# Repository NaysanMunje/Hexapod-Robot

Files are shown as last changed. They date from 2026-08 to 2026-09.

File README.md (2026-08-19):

# Hexapod
a cheap 3D printed hexapod robot using MG996r servos and an esp32.

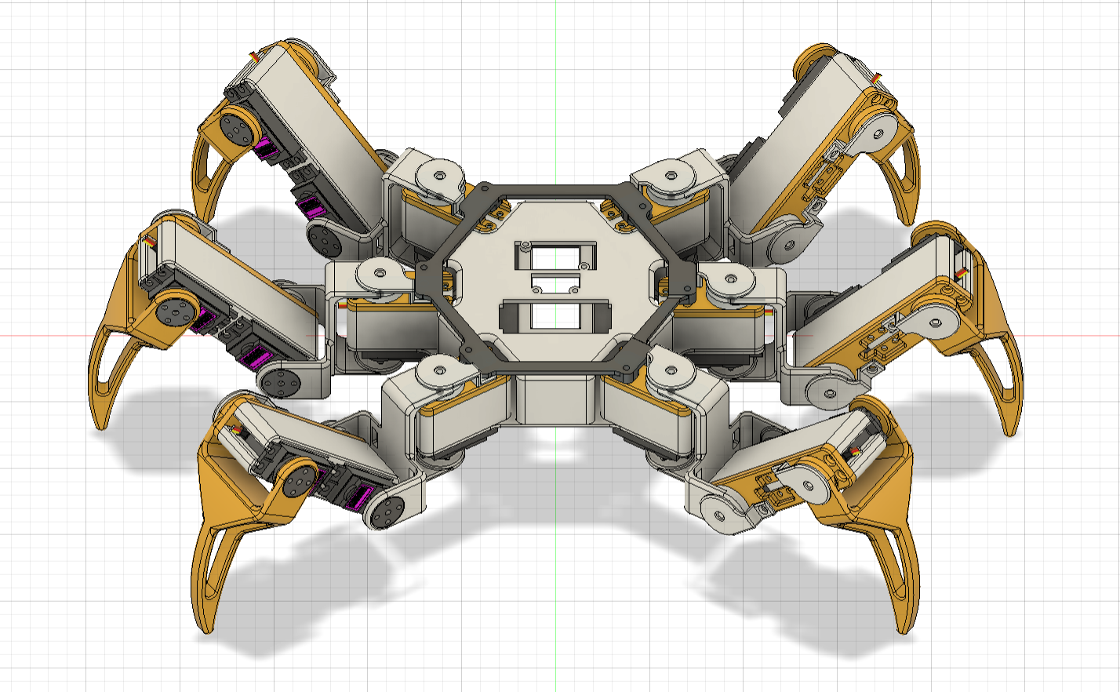
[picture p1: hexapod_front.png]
Hexapod from the front


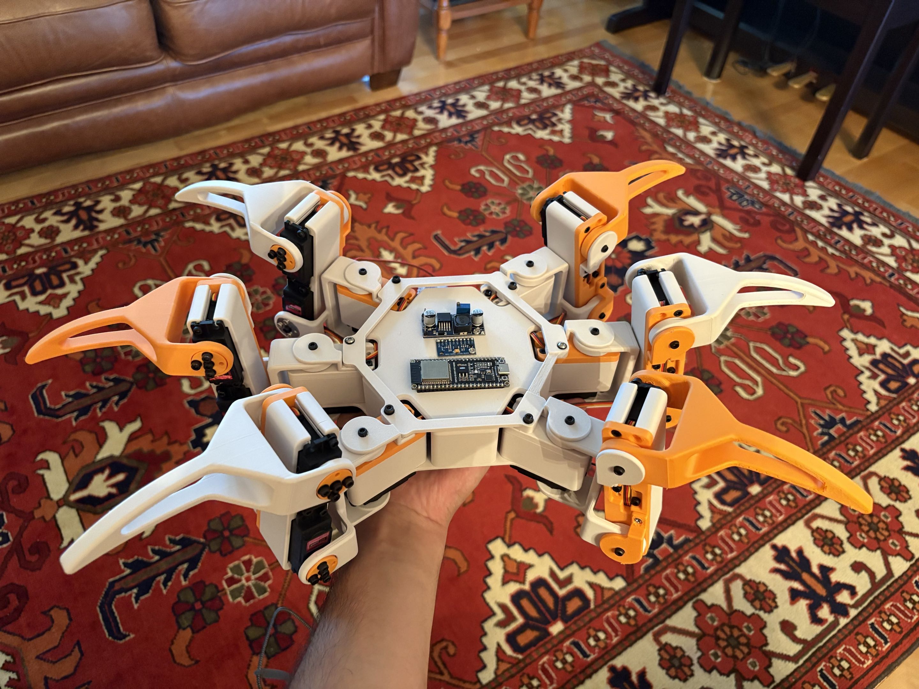
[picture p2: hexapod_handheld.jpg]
Hexapod handheld


How to set up, flash, and run the robot is in **[USAGE.md](USAGE.md)**. Calibration steps are in **[docs/CALIBRATION.md](docs/CALIBRATION.md)**.

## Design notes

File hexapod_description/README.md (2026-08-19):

# Model & preview (`hexapod_description`)

Stick kinematics and URDF matching the firmware. **Offline preview:** open [`view_hexapod.html`](view_hexapod.html) (same gait tabs as `/walk`).

| File | Purpose |
|---|---|
| `view_hexapod.html` | Full robot simulation |
| `view_leg.html` / `view_body.html` | Single leg / chassis |
| `urdf/hexapod.urdf` | Full robot URDF |
| `hips.json` | Hip positions and coxa defaults |

Operator guide: [../USAGE.md](../USAGE.md).

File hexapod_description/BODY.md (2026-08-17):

# Hexapod body (center plate)

## Dimensions (mm)
| Feature | Value |
|---|---|
| Top / bottom edges | **123.215** |
| Other four edges | **79.893** each |
| Top–bottom (flat-to-flat) | **146.564** |
| Left–right tip-to-tip | **186.859** (derived) |
| Height | **30** (hips on the bottom face) |

Opposite sides parallel; left/right symmetric.

## Hip mounts = **vertices** (mm)
Frame: +X forward, +Y left.

| Leg | X | Y |
|-----|---|---|
| **LF** | 73.282 | 61.608 |
| **LM** | 0 | 93.430 |
| **LR** | -73.282 | 61.608 |
| **RF** | 73.282 | -61.608 |
| **RM** | 0 | -93.430 |
| **RR** | -73.282 | -61.608 |

Orientation of each coxa (`yaw0`) is the **mount default**, not radial from center: LM/RM along ±Y; corners perpendicular outward to the adjacent 79.893 mm side. Numbers are in [`hips.json`](hips.json).

## Files
- [`urdf/body.urdf`](urdf/body.urdf)
- [`view_body.html`](view_body.html)
- [`hips.json`](hips.json)

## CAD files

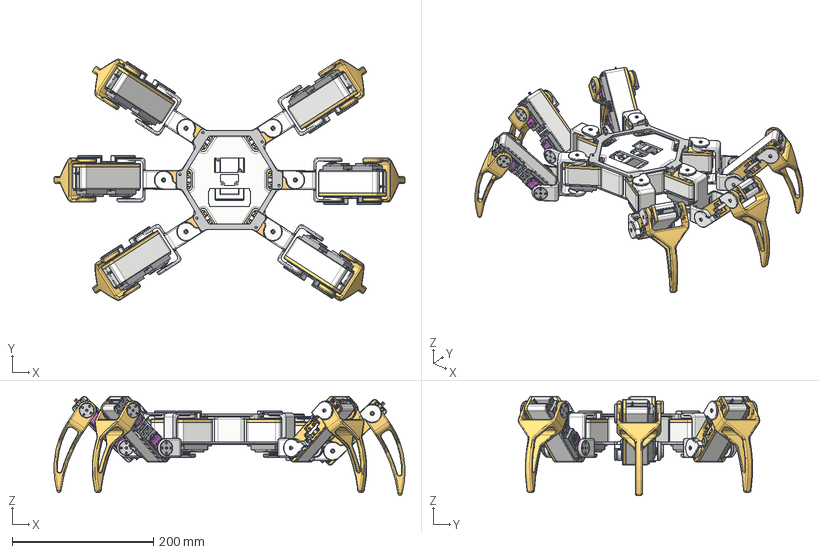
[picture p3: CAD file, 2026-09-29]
FINAL ASSEMBLY.step
497.6 x 342.5 x 140.4 mm
hip servo x 6
hip servo bottom x 6
hip output x 6
thigh link x 6
thigh link bottom plate x 6
shin x 6
bearing insert x 18
servo disc x 18
chassis cap
chassis 2

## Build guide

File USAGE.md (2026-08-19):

# Using the hexapod

This guide takes you from parts on the bench to a walking robot. If something fails, see [docs/TROUBLESHOOTING.md](docs/TROUBLESHOOTING.md).

---

## What you need

| Item | Notes |
|---|---|
| **ESP32-S3 DevKitC-1** | Firmware target in `pca_servo_test/platformio.ini` |
| **18× MG996R-class servos** | One hip, thigh, shin per leg × 6 legs |
| **2× PCA9685** | Addresses **0x40** (default) and **0x41** (A0 bridged to V+) |
| **5 V supply for servos** | Separate from USB; common ground with ESP32 |
| **I²C wiring** | SDA → **GPIO6**, SCL → **GPIO5** |
| **WiFi** | 2.4 GHz network the ESP can join |
| **PC** | [PlatformIO](https://platformio.org/) (VS Code extension or CLI) |

Leg naming on the web UI: **FL, ML, RL** (left) and **FR, MR, RR** (right). Forward is **+X** on the body.

---

## Hardware

### PCA9685 addresses

| Board | I²C address | Channels |
|---|---|---|
| PCA #0 | `0x40` | UI channels 1–16 |
| PCA #1 | `0x41` (A0 jumpered) | UI channels 17–32 |

On boot the serial log must show `PCA0 0x40 ready` and `PCA1 0x41 ready`. If either is **missing/fail**, fix wiring and power before continuing.

### Servo channel map

Each joint has a **UI channel number** (1–32) used on the calibrator page. The full map is in [`pca_servo_test/servo_map.json`](pca_servo_test/servo_map.json). Example:

| Leg | Hip | Thigh | Shin |
|-----|-----|---|---|
| FL | 12 | 8 | 22 |
| ML | 11 | 7 | 21 |
| RL | 10 | 5 | 17 |
| FR | 23 | 19 | 13 |
| MR | 29 | 28 | 9 |
| RR | 26 | 18 | 1 |

If your wiring differs, update `servo_map.json` **and** the `JOINTS[]` table in `src/main.cpp` together (same project; that file is the firmware source of truth for channel numbers).

### Power and safety

- **Never** drive servos from ESP32 3.3 V pins — use the PCA9685 with a proper 5 V servo supply.
- Start calibration with the robot **off the ground** or legs free to move.
- Keep fingers clear when pressing **Start robot** or running **Go MAX/MIN** on the calibrator.
- Stop with **Stop robot** or power off if a joint buzzes against a hard stop.

---

## Software setup

### 1. WiFi credentials

```bash
cd pca_servo_test
```

Copy the example secrets file:

- **Linux / macOS:** `cp include/wifi_secrets.h.example include/wifi_secrets.h`
- **Windows (PowerShell):** `Copy-Item include/wifi_secrets.h.example include/wifi_secrets.h`

Edit `include/wifi_secrets.h` and set `WIFI_SSID` and `WIFI_PASSWORD`.

### 2. Serial port

Default upload port is **COM4** in `platformio.ini`. Change `upload_port` and `monitor_port` to match your board (e.g. `COM3`, `/dev/ttyUSB0`).

Find the port: Device Manager (Windows), `pio device list`, or the PlatformIO toolbar.

### 3. Flash firmware

```bash
pio run -t upload
pio device monitor
```

At 115200 baud you should see:

1. I²C scan finding `0x40` and `0x41`
2. PCA ready messages
3. WiFi connecting, then **`Open http://192.168.x.x`**

Connect your phone or PC to the **same WiFi** and open that URL.

### 4. Pre-loaded calibration (this repo’s robot)

If your hardware matches this build, firmware may already work: on **empty NVS** it loads [`calibration/servo_cal.json`](calibration/servo_cal.json) automatically.

**Check:** calibrator page (`http://<ip>/`) should show **18/18 calibrated**. If counts are lower or motion looks wrong, follow **[docs/CALIBRATION.md](docs/CALIBRATION.md)**.

---

## Web pages

| URL | Use |
|-----|-----|
| `http://<ip>/` | **Calibration** — set DEFAULT/MAX, direction, lock spans |
| `http://<ip>/walk` | **Gaits** — preview, deploy params, start/stop robot |

The walk page loads Three.js from a CDN when you open **Settings** → 3D preview. The browser needs **internet** for that panel only; tabs and robot control work offline once the page is loaded.

---

## Walk page (`/walk`)

### Layout

- **Top tabs:** Walk · Ripple · Wave · Spin · Stretch · Pitch · Crouch · Twist · Roll · Nod · Swirl · Rotate · Control
- **Settings** (overlay): sliders, 3D preview, **Deploy to robot**, **Freeze hips**
- **Start robot / Stop robot** on the main screen (except Control tab, which uses hold-to-move)

### Important behavior

| Action | What it does |
|---|---|
| Move sliders | Updates **preview** (and 3D if Settings open) only |
| **Deploy to robot** | Sends current sliders to the ESP; required before walking |
| **Start robot** | Runs the active tab’s motion on hardware |
| **Stop robot** | Stops gait; parks legs (hips default, shins mid, thighs 75% toward min) |
| **Freeze hips** | Coxa stay at default; thighs/shins still walk (good first setting) |

Sliders do **not** live-update the robot until you deploy.

### Recommended first walk

1. Tab: **Walk**
2. Settings: leave defaults if unsure — **freq 0.8 Hz**, **stride 60 mm**, **lift 30 mm**, **height 95 mm**, **radius 140 mm**, **splay 22°**, **Freeze hips** on
3. **Deploy to robot**
4. Lift robot clear of the table → **Start robot**
5. If motion is smooth, try lowering stride or freq; if feet drag, increase lift slightly
6. **Stop robot** when done

### Tabs (short)

| Tab | Motion |
|-----|---|
| **Walk** | Tripod gait (3+3), 50% duty — default forward walk |
| **Ripple** | One leg at a time, alternating sides rear→front |
| **Wave** | One leg at a time clockwise around the body |
| **Spin** | In-place yaw; set **turn rate** in Settings; stride should be 0 |
| **Stretch** | Feet planted · lean left ↔ right (**Start robot**) |
| **Pitch** | Feet planted · lean forward ↔ back |
| **Crouch** | Feet planted · squat up ↔ down |
| **Twist** | Feet planted · yaw left ↔ right (uncheck Freeze hips) |
| **Roll** | Feet planted · chassis tilts left ↔ right (~14°) |
| **Nod** | Feet planted · chassis tips nose ↔ tail (~14°) |
| **Swirl** | Feet planted · chassis tilts while circling (most motion) |
| **Rotate** | Feet planted · lean in a circle (body stays level) |
| **Control** | Hold D-pad to walk; hold **↺ CCW** / **↻ CW** to spin; release to stop |

Switching away from a locomotion tab **stops** the robot if it was running.

### Spin and Control

- **Spin tab:** deploy with **turn rate** (default 20°/s), **stride 0**, then **Start robot**
- **Control tab:** turn rate comes from Settings; hold spin buttons while deployed

Keep turn rate modest (~15–25°/s) until you confirm hips are not saturating.

---

## Calibration (summary)

Full procedure: **[docs/CALIBRATION.md](docs/CALIBRATION.md)**.

Quick rules:

1. **Hip:** mechanical default → **Save DEFAULT** → set direction (+CCW from above)
2. **Thigh / shin:** folded hard stop → **Save MAX** → set direction (+pulse opens toward straight)
3. After all 12 thighs and 12 shins have MAX saved: **Lock thighs/shins to shortest max→min span**
4. Use **Go MIN / Go MID / Go MAX** on each joint to verify before walking

Reference: **[pca_servo_test/JOINT_CONVENTION.md](pca_servo_test/JOINT_CONVENTION.md)**.

---

## Offline simulation

Open [`hexapod_description/view_hexapod.html`](hexapod_description/view_hexapod.html) locally. Tune gaits and clearances without hardware. Defaults match the firmware walk page.

Other viewers: `view_leg.html` (single leg), `view_body.html` (chassis).

---

## Maintainers: editing the walk UI

After changing `pca_servo_test/www/walk.html`:

```bash
cd pca_servo_test
python gen_walk_html.py
pio run -t upload
```

After re-calibrating and downloading JSON from the robot:

```bash
# save to calibration/servo_cal.json, then:
python gen_cal_backup.py
pio run -t upload
```

See [calibration/README.md](calibration/README.md).

---

## Checklist before first walk

- [ ] Both PCA boards detected on serial boot
- [ ] Calibrator shows 18/18 (or calibration finished per CALIBRATION.md)
- [ ] **Lock spans** run for thighs and shins
- [ ] **Deploy to robot** clicked after slider changes
- [ ] Robot supported or clear of obstacles
- [ ] **Stop robot** tested

Done — use [docs/TROUBLESHOOTING.md](docs/TROUBLESHOOTING.md) if anything misbehaves.

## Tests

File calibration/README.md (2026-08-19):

# Calibration backup

Example PWM table for this robot: [`servo_cal.json`](servo_cal.json).

| Task | Doc |
|---|-----|
| Calibrate a new build | [../docs/CALIBRATION.md](../docs/CALIBRATION.md) |
| Joint angles & PWM math | [../pca_servo_test/JOINT_CONVENTION.md](../pca_servo_test/JOINT_CONVENTION.md) |

**Restore on device:** calibrator → **Restore snapshot**, or auto-load on empty NVS.

**Refresh backup after re-cal:** download JSON from robot → replace `servo_cal.json` → `python gen_cal_backup.py` in `pca_servo_test/` → re-flash.

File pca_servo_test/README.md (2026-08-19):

# Firmware (`pca_servo_test`)

| Task | Doc |
|---|-----|
| Flash, walk UI, first steps | [../USAGE.md](../USAGE.md) |
| Calibrate servos | [../docs/CALIBRATION.md](../docs/CALIBRATION.md) |
| Fix problems | [../docs/TROUBLESHOOTING.md](../docs/TROUBLESHOOTING.md) |
| Joint convention | [JOINT_CONVENTION.md](JOINT_CONVENTION.md) |
| Channel wiring | [servo_map.json](servo_map.json) |

```bash
cp include/wifi_secrets.h.example include/wifi_secrets.h   # then edit WiFi
pio run -t upload
```

After editing `www/walk.html`: `python gen_walk_html.py` then re-flash.

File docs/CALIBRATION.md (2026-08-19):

# Servo calibration

Follow this on a **new build**, after rewiring, or if legs move the wrong way. The robot should be **off the ground** and powered.

**Reference while you work:** [JOINT_CONVENTION.md](../pca_servo_test/JOINT_CONVENTION.md) (angles, signs, PWM rules).

**Channel numbers:** [servo_map.json](../pca_servo_test/servo_map.json).

---

## Before you start

1. Flash firmware and open **`http://<esp-ip>/`** (calibrator).
2. Serial log should show `PCA0 0x40 ready` and `PCA1 0x41 ready`.
3. Status line should show how many joints are calibrated (goal: **18/18**).

If this repo’s hardware matches yours, try a quick test first: firmware may load [servo_cal.json](../calibration/servo_cal.json) from flash backup. Use **Restore snapshot from firmware backup** on the calibrator page. If all legs move correctly on **Go MID**, you can skip to the lock-span step below.

---

## Calibrator page overview

Each joint row has:

| Control | Purpose |
|---|---|
| Slider + **− / +** | Nudge raw PWM (80–520 µs ticks) |
| **Save DEFAULT** (hip only) | Current pose = model 0° |
| **Save MAX** (thigh/shin) | Current folded hard stop = model MAX |
| **← MIN / MIN →** (or **← +CCW / +CCW →** on hips) | Set direction: higher PWM toward model MIN |
| **Go MAX / Go MID / Go MIN** | Jump to calibrated endpoints |

Global buttons at the top:

- **Lock thighs/shins to shortest max→min span** — run after all thighs and shins have MAX saved
- **All … → MID/MIN/MAX** — test groups
- **Restore snapshot** — load committed JSON from firmware

---

## Order of work

Work **one joint at a time** or leg-by-leg (hip → thigh → shin on FL, then next leg, …). Thighs and shins **must** be calibrated before walking.

### Step 1 — All hips (6 joints)

For each hip:

1. Rotate coxa by hand or slider until the leg matches the **mount default** (middle legs along ±Y; corners outward — see JOINT_CONVENTION).
2. Click **Save DEFAULT**.
3. Tap **← +CCW** or **+CCW →** so that **increasing PWM moves the foot clockwise from above** (toward model MIN = −45°).
4. Test: **Go MAX** ≈ CCW from default; **Go MIN** ≈ CW from default.

Hips do **not** use Save MAX at a mechanical stop.

### Step 2 — All thighs (6 joints)

For each thigh:

1. Move to the **folded hard stop** (femur up against hip / maximum fold).
2. Click **Save MAX**.
3. Set direction so **+pulse opens the thigh toward flat** (model MIN = straight).
4. Test: **Go MIN** extends thigh; **Go MID** halfway; **Go MAX** folded.

### Step 3 — All shins (6 joints)

For each shin:

1. Move to **folded hard stop** (foot under thigh).
2. Click **Save MAX**.
3. Set direction so **+pulse straightens** the shin (model MIN).
4. Test: **Go MIN** straight; **Go MID** halfway; **Go MAX** folded.

### Step 4 — Lock spans

When all 12 thighs and 12 shins have `ref` saved:

1. Click **Lock thighs/shins to shortest max→min span**.
2. Serial / status should confirm locked spans (this build uses ~226 ticks thigh, ~203 shin when all legs match).

Locking keeps all six legs on the same usable range even if one servo has slightly less travel.

### Step 5 — Verify

1. **All calibrated → MID / DEFAULT** — robot should sit in a symmetric rest-like pose.
2. Move each leg through **Go MIN** and **Go MAX** once — no buzzing for more than a moment at stops.
3. Download **calibration JSON** from the page and save to `calibration/servo_cal.json` if you want the backup committed (optional).

---

## Direction mistakes (most common error)

Symptom: **Go MIN** moves the wrong way or hits a stop immediately.

Fix: flip **MIN ← / → MIN** (or hip **+CCW** side), then re-test MIN/MID/MAX. You do **not** need to re-save ref unless the reference pose was wrong.

---

## After calibration

1. Open **`/walk`**
2. **Deploy to robot**
3. Try **Walk** tab with **Freeze hips** on and low stride

If gait IK reports unreachable feet, check **height**, **radius**, and **lift** in Settings — start from defaults (95 mm height, 140 mm radius).

---

## Saving calibration into firmware

To bake your table into the next flash for other boards:

```bash
cd pca_servo_test
python gen_cal_backup.py   # reads ../calibration/servo_cal.json
pio run -t upload
```

Empty NVS on a new chip will then auto-restore your snapshot on boot.

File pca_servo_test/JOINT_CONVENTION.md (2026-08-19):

# Joint rotation standard (model ↔ servos)

**Calibrating hardware?** Use the step-by-step guide: [docs/CALIBRATION.md](../docs/CALIBRATION.md).

Robot frame: **+X forward, +Y left, +Z up**.  
All six legs use the **same** kinematic signs (no left/right axis flip in the model). Servo mounting mirrors are handled only by each joint’s **direction** flag in calibration.

Naming: UI `FL/ML/RL/FR/MR/RR` = model `LF/LM/LR/RF/RM/RR`.

PWM snapshot for this robot: [`../calibration/servo_cal.json`](../calibration/servo_cal.json).

---

## Zero poses

| Joint | Angle 0 (model) |
|---|---|
| **Hip** | Mount default: middle legs horizontal (±Y); corners perpendicular **outward** to the adjacent **79.893 mm** body edge (`yaw0` in `hips.json`) |
| **Thigh** | Femur horizontal in the coxa’s radial plane (collinear with coxa, flat) |
| **Shin** | Shin collinear with thigh (fully open) |

---

## Hip (special)

Hips are **not** calibrated to min/max stops. Only the **mount default** is saved (mid / model 0°).

- Side buttons mark which slider direction is **+CCW from above** (`← +CCW` / `+CCW →`).
- Gait later uses `pulse = default + scale * (−θ)` with that direction (θ = model hip angle).
- Soft ±45° limits can be applied in software without calibrating those PWM ends.

## Thigh / shin

Still calibrate from **MAX** hard stop; MIN = remaining travel; MID = midpoint.
Side buttons: **MIN ←** / **→ MIN**.

---

## Positive model angles (same on every leg)

| Joint | + direction | Range | MAX | MIN |
|---|---|---|-----|-----|
| **Hip** | **CCW from above** (right-hand about +Z). Foot swings counterclockwise around the body from the default. | −45° … +45° | +45° (CCW) | −45° (CW) |
| **Thigh** | Femur tip / knee **rises** (pitch up from horizontal) | 0° … 102.5° | **102.5°** hard stop (thigh folded toward hip) | **0°** (straight / flat) |
| **Shin** | Foot folds **back under** the thigh (knee bend) | 0° … 122.4° | **122.4°** hard stop (shin folded) | **0°** (straight with thigh) |

These are exactly the signs used by `view_hexapod.html` IK / gait.

---

## How to set servo direction in the calibrator

Calibration stores one reference pulse, then derives the rest. **Direction** answers:

> Does **increasing PWM** move the joint toward **model MIN**?

| `dir` | Meaning |
|---|---|
| **+ pulse** | Higher PWM → toward model MIN |
| **− pulse** | Higher PWM → toward model MAX (i.e. lower PWM → MIN) |

### Hip
1. Align coxa to **mount default** → **Save DEFAULT** (this is model 0° / mid).
2. Nudge PWM. Watch the foot from above.
3. Pick direction so **+pulse moves CW from above** (toward model MIN = −45°).
4. Check: **Go MAX** = CCW from default; **Go MIN** = CW from default.

### Thigh
1. Ease to the **folded hard stop** (thigh up against hip) → **Save MAX**.
2. Pick direction so **+pulse opens the thigh toward flat/straight** (model MIN).
3. Check: **Go MIN** lowers/extends the thigh; **Go MID** is halfway.

### Shin
1. Ease to the **folded hard stop** → **Save MAX**.
2. Pick direction so **+pulse opens the shin toward straight** (model MIN).
3. Check: **Go MIN** straightens the shin; **Go MID** is halfway.

---

## Mapping model angle → PWM (firmware)

Once `ref` and `dir` are set:

**Hip** (`ref` = default):  
`pulse(θ) = ref + dir * ticks_per_deg * (−θ)`  
so θ = +45° (MAX) and θ = −45° (MIN) land on the derived endpoints.

**Thigh / shin** (`ref` = MAX):  
`pulse(θ) = ref + dir * ticks_per_deg * (θ_max − θ)`  
so θ = θ_max → `ref`, θ = 0 → derived MIN.

(`ticks_per_deg ≈ 400/180` with the current PCA pulse scale.)

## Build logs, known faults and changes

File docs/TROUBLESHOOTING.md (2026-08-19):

# Troubleshooting

Symptoms → checks → fixes. Start with serial monitor output (115200 baud) while reproducing the issue.

---

## WiFi / web page

| Symptom | Fix |
|---|-----|
| Serial stuck at `Connecting...` | Wrong SSID/password in `wifi_secrets.h`; ESP must be on **2.4 GHz**; re-flash after edit |
| No IP printed | Wait 30 s; check router; try serial-only calibrator features if WiFi fails |
| Phone cannot open `http://<ip>` | PC/phone on **same network** as ESP; disable VPN; try IP from serial exactly |
| `/walk` loads but 3D blank | Browser needs **internet** for Three.js CDN; rest of page still works |

---

## I²C / PCA9685

| Symptom | Fix |
|---|-----|
| `PCA0 missing/fail` | Check SDA/SCL (GPIO6/5), 3.3 V logic, common ground |
| Only one board found | Second board needs **A0 → V+** for address **0x41** |
| I²C scan finds nothing | Loose wires, wrong pins, or flat battery on ESP32 |
| One leg dead, others OK | Match [servo_map.json](../pca_servo_test/servo_map.json) wiring to UI channel; test with calibrator slider on that channel |

---

## Servos

| Symptom | Fix |
|---|-----|
| Servo buzzes at stop | Normal briefly at MIN/MAX; back off slider; recalibrate MAX if stop moved |
| Wrong joint moves | Wrong channel in `servo_map.json` / firmware `JOINTS[]` |
| Leg moves backward vs preview | Flip **dir** on that joint (see [CALIBRATION.md](CALIBRATION.md)) |
| Jerky or weak motion | Servo power supply undervoltage; add bulk cap; separate 5 V from USB |
| All servos twitch at boot | Expected short pulse; ensure supply can deliver 18 servos |

---

## Calibration count

| Symptom | Fix |
|---|-----|
| Less than 18/18 calibrated | Finish hips (DEFAULT), thighs/shins (MAX) per [CALIBRATION.md](CALIBRATION.md) |
| Restore did nothing | Click **Restore snapshot from firmware backup** on `/` or re-flash after `gen_cal_backup.py` |
| Values look random | NVS corrupt — restore snapshot or full re-cal |

---

## Walk / gait (`/walk`)

| Symptom | Fix |
|---|-----|
| Sliders move preview but not robot | Click **Deploy to robot** |
| Start does nothing | Deploy first; check 18/18 calibrated; serial for errors |
| Robot walks before Start | Only **Start robot** runs motion; switching tabs stops robot |
| Feet don’t lift | Increase **lift**; decrease **stride** or **freq** |
| Hips pegged / leg skips | Lower **turn** rate; disable spin until walk is good; try **Freeze hips** |
| “Unreachable” / bad pose in status | Lower **height** or **radius**; increase **splay** on corners |
| Stretch/Rotate won’t run | Must press **Start robot** on that tab (no auto-start) |
| Control hold doesn’t move | Deploy first; hold D-pad or spin buttons; release to stop |
| Stop pose wrong | **Stop robot** parks thighs between mid and min; hips default — expected |

---

## Flash / PlatformIO

| Symptom | Fix |
|---|-----|
| Upload fails | Fix `upload_port` in `platformio.ini`; hold BOOT if needed; USB cable data-capable |
| `pio` not found | Install PlatformIO IDE extension or CLI |
| Windows `cp` fails | Use `Copy-Item` for `wifi_secrets.h` |

---

## Simulation vs robot diverge

| Symptom | Fix |
|---|-----|
| Preview OK, hardware wrong | Calibration / direction issue, not gait math |
| Preview wrong | Open `hexapod_description/view_hexapod.html`; compare link lengths in [hips.json](../hexapod_description/hips.json) to your physical robot |

---

## Still stuck?

1. Serial log from cold boot through first **Start robot**
2. Calibrator **Download calibration JSON** attached to an issue
3. Confirm PCA scan, calibrated count, and which tab + slider values were deployed

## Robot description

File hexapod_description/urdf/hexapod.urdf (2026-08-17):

<?xml version="1.0"?>
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
<robot name="hexapod">
  <link name="base_link">
    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
  </link>

  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
  <joint name="LF_attach" type="fixed">
    <parent link="base_link"/>
    <child link="LF_hip"/>
    <origin xyz="0.073282 0.061608 0" rpy="0 0 1.161125"/>
  </joint>
  <link name="LF_hip"/>

  <joint name="LF_coxa_joint" type="revolute">
    <parent link="LF_hip"/>
    <child link="LF_coxa"/>
    <origin xyz="0 0 0" rpy="0 0 0"/>
    <axis xyz="0 0 1"/>
    <limit lower="-0.785" upper="0.785" effort="10" velocity="3"/>
  </joint>
  <link name="LF_coxa">
    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
  </link>

  <joint name="LF_femur_joint" type="revolute">
    <parent link="LF_coxa"/>
    <child link="LF_femur"/>
    <origin xyz="0.053 0 0" rpy="0 0 0"/>
    <axis xyz="0 1 0"/>
    <limit lower="-1.789" upper="0" effort="10" velocity="3"/>
  </joint>
  <link name="LF_femur">
    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
  </link>

  <joint name="LF_knee_joint" type="revolute">
    <parent link="LF_femur"/>
    <child link="LF_shin1"/>
    <origin xyz="0.07736 0 0" rpy="0 0 0"/>
    <axis xyz="0 1 0"/>
    <limit lower="0" upper="2.136" effort="10" velocity="3"/>
  </joint>
  <link name="LF_shin1">
    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
  </link>

  <joint name="LF_shin1_shin2" type="fixed">
    <parent link="LF_shin1"/>
    <child link="LF_shin2"/>
    <origin xyz="0.022358 0 0" rpy="0 -0.2234 0"/>
  </joint>
  <link name="LF_shin2">
    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
  </link>

  <joint name="LF_shin2_shin3" type="fixed">
    <parent link="LF_shin2"/>
    <child link="LF_shin3"/>
    <origin xyz="0.071518 0 0" rpy="0 -0.3508 0"/>
  </joint>
  <link name="LF_shin3">
    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
  </link>

  <joint name="LF_foot_fixed" type="fixed">
    <parent link="LF_shin3"/>
    <child link="LF_foot"/>
    <origin xyz="0.03114 0 0" rpy="0 0 0"/>
  </joint>
  <link name="LF_foot">
    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
  </link>

  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
  <joint name="LM_attach" type="fixed">
    <parent link="base_link"/>
    <child link="LM_hip"/>
    <origin xyz="0.000000 0.093430 0" rpy="0 0 1.570796"/>
  </joint>
  <link name="LM_hip"/>

  <joint name="LM_coxa_joint" type="revolute">
    <parent link="LM_hip"/>
    <child link="LM_coxa"/>
    <origin xyz="0 0 0" rpy="0 0 0"/>
    <axis xyz="0 0 1"/>
    <limit lower="-0.785" upper="0.785" effort="10" velocity="3"/>
  </joint>
  <link name="LM_coxa">
    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
  </link>

  <joint name="LM_femur_joint" type="revolute">
    <parent link="LM_coxa"/>
    <child link="LM_femur"/>
    <origin xyz="0.053 0 0" rpy="0 0 0"/>
    <axis xyz="0 1 0"/>
    <limit lower="-1.789" upper="0" effort="10" velocity="3"/>
  </joint>
  <link name="LM_femur">
    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
  </link>

  <joint name="LM_knee_joint" type="revolute">
    <parent link="LM_femur"/>
    <child link="LM_shin1"/>
    <origin xyz="0.07736 0 0" rpy="0 0 0"/>
    <axis xyz="0 1 0"/>
    <limit lower="0" upper="2.136" effort="10" velocity="3"/>
  </joint>
  <link name="LM_shin1">
    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
  </link>

  <joint name="LM_shin1_shin2" type="fixed">
    <parent link="LM_shin1"/>
    <child link="LM_shin2"/>
    <origin xyz="0.022358 0 0" rpy="0 -0.2234 0"/>
  </joint>
  <link name="LM_shin2">
    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
  </link>

  <joint name="LM_shin2_shin3" type="fixed">
    <parent link="LM_shin2"/>
    <child link="LM_shin3"/>
    <origin xyz="0.071518 0 0" rpy="0 -0.3508 0"/>
  </joint>
  <link name="LM_shin3">
    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
  </link>

  <joint name="LM_foot_fixed" type="fixed">
    <parent link="LM_shin3"/>
    <child link="LM_foot"/>
    <origin xyz="0.03114 0 0" rpy="0 0 0"/>
  </joint>
  <link name="LM_foot">
    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
  </link>

  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
  <joint name="LR_attach" type="fixed">
    <parent link="base_link"/>
    <child link="LR_hip"/>
    <origin xyz="-0.073282 0.061608 0" rpy="0 0 1.980468"/>
  </joint>
  <link name="LR_hip"/>

  <joint name="LR_coxa_joint" type="revolute">
    <parent link="LR_hip"/>
    <child link="LR_coxa"/>
    <origin xyz="0 0 0" rpy="0 0 0"/>
    <axis xyz="0 0 1"/>
    <limit lower="-0.785" upper="0.785" effort="10" velocity="3"/>
  </joint>
  <link name="LR_coxa">
    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
  </link>

  <joint name="LR_femur_joint" type="revolute">
    <parent link="LR_coxa"/>
    <child link="LR_femur"/>
    <origin xyz="0.053 0 0" rpy="0 0 0"/>
    <axis xyz="0 1 0"/>
    <limit lower="-1.789" upper="0" effort="10" velocity="3"/>
  </joint>
  <link name="LR_femur">
    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
  </link>

  <joint name="LR_knee_joint" type="revolute">
    <parent link="LR_femur"/>
    <child link="LR_shin1"/>
    <origin xyz="0.07736 0 0" rpy="0 0 0"/>
    <axis xyz="0 1 0"/>
    <limit lower="0" upper="2.136" effort="10" velocity="3"/>
  </joint>
  <link name="LR_shin1">
    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
  </link>

  <joint name="LR_shin1_shin2" type="fixed">
    <parent link="LR_shin1"/>
    <child link="LR_shin2"/>
    <origin xyz="0.022358 0 0" rpy="0 -0.2234 0"/>
  </joint>
  <link name="LR_shin2">
    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
  </link>

  <joint name="LR_shin2_shin3" type="fixed">
    <parent link="LR_shin2"/>
    <child link="LR_shin3"/>
    <origin xyz="0.071518 0 0" rpy="0 -0.3508 0"/>
  </joint>
  <link name="LR_shin3">
    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
  </link>

  <joint name="LR_foot_fixed" type="fixed">
    <parent link="LR_shin3"/>
    <child link="LR_foot"/>
    <origin xyz="0.03114 0 0" rpy="0 0 0"/>
  </joint>
  <link name="LR_foot">
    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
  </link>

  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
  <joint name="RF_attach" type="fixed">
    <parent link="base_link"/>
    <child link="RF_hip"/>
    <origin xyz="0.073282 -0.061608 0" rpy="0 0 -1.161125"/>
  </joint>
  <link name="RF_hip"/>

  <joint name="RF_coxa_joint" type="revolute">
    <parent link="RF_hip"/>
    <child link="RF_coxa"/>
    <origin xyz="0 0 0" rpy="0 0 0"/>
    <axis xyz="0 0 1"/>
    <limit lower="-0.785" upper="0.785" effort="10" velocity="3"/>
  </joint>
  <link name="RF_coxa">
    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
  </link>

  <joint name="RF_femur_joint" type="revolute">
    <parent link="RF_coxa"/>
    <child link="RF_femur"/>
    <origin xyz="0.053 0 0" rpy="0 0 0"/>
    <axis xyz="0 1 0"/>
    <limit lower="-1.789" upper="0" effort="10" velocity="3"/>
  </joint>
  <link name="RF_femur">
    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
  </link>

  <joint name="RF_knee_joint" type="revolute">
    <parent link="RF_femur"/>
    <child link="RF_shin1"/>
    <origin xyz="0.07736 0 0" rpy="0 0 0"/>
    <axis xyz="0 1 0"/>
    <limit lower="0" upper="2.136" effort="10" velocity="3"/>
  </joint>
  <link name="RF_shin1">
    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
  </link>

  <joint name="RF_shin1_shin2" type="fixed">
    <parent link="RF_shin1"/>
    <child link="RF_shin2"/>
    <origin xyz="0.022358 0 0" rpy="0 -0.2234 0"/>
  </joint>
  <link name="RF_shin2">
    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
  </link>

  <joint name="RF_shin2_shin3" type="fixed">
    <parent link="RF_shin2"/>
    <child link="RF_shin3"/>
    <origin xyz="0.071518 0 0" rpy="0 -0.3508 0"/>
  </joint>
  <link name="RF_shin3">
    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
  </link>

  <joint name="RF_foot_fixed" type="fixed">
    <parent link="RF_shin3"/>
    <child link="RF_foot"/>
    <origin xyz="0.03114 0 0" rpy="0 0 0"/>
  </joint>
  <link name="RF_foot">
    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
  </link>

  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
  <joint name="RM_attach" type="fixed">
    <parent link="base_link"/>
    <child link="RM_hip"/>
    <origin xyz="0.000000 -0.093430 0" rpy="0 0 -1.570796"/>
  </joint>
  <link name="RM_hip"/>

  <joint name="RM_coxa_joint" type="revolute">
    <parent link="RM_hip"/>
    <child link="RM_coxa"/>
    <origin xyz="0 0 0" rpy="0 0 0"/>
    <axis xyz="0 0 1"/>
    <limit lower="-0.785" upper="0.785" effort="10" velocity="3"/>
  </joint>
  <link name="RM_coxa">
    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
  </link>

  <joint name="RM_femur_joint" type="revolute">
    <parent link="RM_coxa"/>
    <child link="RM_femur"/>
    <origin xyz="0.053 0 0" rpy="0 0 0"/>
    <axis xyz="0 1 0"/>
    <limit lower="-1.789" upper="0" effort="10" velocity="3"/>
  </joint>
  <link name="RM_femur">
    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
  </link>

  <joint name="RM_knee_joint" type="revolute">
    <parent link="RM_femur"/>
    <child link="RM_shin1"/>
    <origin xyz="0.07736 0 0" rpy="0 0 0"/>
    <axis xyz="0 1 0"/>
    <limit lower="0" upper="2.136" effort="10" velocity="3"/>
  </joint>
  <link name="RM_shin1">
    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
  </link>
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

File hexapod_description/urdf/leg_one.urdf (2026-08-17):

<?xml version="1.0"?>
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
<robot name="hexapod_leg">

  <link name="base_link">
    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
  </link>

  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
  <joint name="coxa_joint" type="revolute">
    <parent link="base_link"/>
    <child link="coxa_link"/>
    <origin xyz="0 0 0" rpy="0 0 0"/>
    <axis xyz="0 0 1"/>
    <limit lower="-1.5708" upper="1.5708" effort="10" velocity="3"/>
  </joint>

  <link name="coxa_link">
    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
  </link>

  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
  <joint name="femur_joint" type="revolute">
    <parent link="coxa_link"/>
    <child link="femur_link"/>
    <origin xyz="0.053 0 0" rpy="0 0 0"/>
    <axis xyz="0 1 0"/>
    <limit lower="-1.789" upper="0" effort="10" velocity="3"/>
  </joint>

  <link name="femur_link">
    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
  </link>

  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
  <joint name="knee_joint" type="revolute">
    <parent link="femur_link"/>
    <child link="shin1_link"/>
    <origin xyz="0.07736 0 0" rpy="0 0 0"/>
    <axis xyz="0 1 0"/>
    <limit lower="0" upper="2.136" effort="10" velocity="3"/>
  </joint>

  <link name="shin1_link">
    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
  </link>

  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
  <joint name="shin1_shin2_fixed" type="fixed">
    <parent link="shin1_link"/>
    <child link="shin2_link"/>
    <origin xyz="0.022358 0 0" rpy="0 0.2234 0"/>
  </joint>

  <link name="shin2_link">
    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
  </link>

  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
  <joint name="shin2_shin3_fixed" type="fixed">
    <parent link="shin2_link"/>
    <child link="shin3_link"/>
    <origin xyz="0.071518 0 0" rpy="0 0.3508 0"/>
  </joint>

  <link name="shin3_link">
    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
  </link>

  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
  <joint name="foot_fixed" type="fixed">
    <parent link="shin3_link"/>
    <child link="foot_link"/>
    <origin xyz="0.03114 0 0" rpy="0 0 0"/>
  </joint>

  <link name="foot_link">
    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
  </link>

</robot>

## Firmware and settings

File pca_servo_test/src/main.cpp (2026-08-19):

// ESP32-S3 firmware: PCA9685 servo calibration + tripod walk.
//
// Hardware
//   I2C SDA=GPIO6, SCL=GPIO5
//   PCA9685 0x40 (UI servos 1–16) and 0x41 A0 bridged (UI 17–32)
//   18 MG996R-class joints; map in servo_map.json / JOINTS[] below
//
// Calibration (NVS namespace "servo_cal")
//   Hip:  ref = mount DEFAULT (model 0°). No min/max stops.
//   Thigh/shin: ref = folded MAX. MIN/MID derived from span and dir.
//   dir = +1 means higher PWM moves toward model MIN.
//   Thigh/shin spans are locked to the shortest available max→min.
//   Snapshot: calibration/servo_cal.json (compiled into calibration_backup.h).
//
// Joint signs: pca_servo_test/JOINT_CONVENTION.md
// Gait: src/walk.cpp (same IK as hexapod_description/view_hexapod.html)
// Web:  /  calibration   /walk  gait preview (walk + spin tabs)

#include <Arduino.h>
#include <WiFi.h>
#include <WebServer.h>
#include <Wire.h>
#include <Preferences.h>
#include <Adafruit_PWMServoDriver.h>
#include "wifi_secrets.h"
#include "walk.h"
#include "gait_preview_html.h"
#include "calibration_backup.h"

static const int SDA_PIN = 6;  // ESP32-S3 I2C data
static const int SCL_PIN = 5;  // ESP32-S3 I2C clock

Adafruit_PWMServoDriver pwm0 = Adafruit_PWMServoDriver(0x40);
Adafruit_PWMServoDriver pwm1 = Adafruit_PWMServoDriver(0x41);
WebServer server(80);
Preferences prefs;

// PCA9685 tick window used for MG996R-class (~0.5–2.5 ms at 50 Hz).
static const uint16_t PULSE_LO = 80;
static const uint16_t PULSE_HI = 520;
static const uint16_t PULSE_DEFAULT = 300;
static const uint8_t SERVO_COUNT = 32;
static const float TICKS_PER_DEG = 400.0f / 180.0f;

// ui is the 1-based number on the 32-channel calibrator page.
// board 0 = ui 1–16 (PCA 0x40 ch 0–15); board 1 = ui 17–32 (PCA 0x41 ch 0–15).
struct JointMap {
  const char *leg;
  const char *joint;
  uint8_t ui;
};
static const JointMap JOINTS[] = {
  {"FL", "hip", 12}, {"FL", "thigh", 8}, {"FL", "shin", 22},
  {"ML", "hip", 11}, {"ML", "thigh", 7}, {"ML", "shin", 21},
  {"RL", "hip", 10}, {"RL", "thigh", 5}, {"RL", "shin", 17},
  {"FR", "hip", 23}, {"FR", "thigh", 19}, {"FR", "shin", 13},
  {"MR", "hip", 29}, {"MR", "thigh", 28}, {"MR", "shin", 9},
  {"RR", "hip", 26}, {"RR", "thigh", 18}, {"RR", "shin", 1},
};
static const uint8_t JOINT_COUNT = sizeof(JOINTS) / sizeof(JOINTS[0]);

static bool isHip(uint8_t ji) { return !strcmp(JOINTS[ji].joint, "hip"); }
static bool isThigh(uint8_t ji) { return !strcmp(JOINTS[ji].joint, "thigh"); }
static bool isShin(uint8_t ji) { return !strcmp(JOINTS[ji].joint, "shin"); }

// Thigh/shin: full travel from MAX stop. Hip: ±45° about mount default.
static float jointHalfOrFullDeg(uint8_t ji) {
  if (isHip(ji)) return 45.0f;
  if (isThigh(ji)) return 102.5f;
  if (isShin(ji)) return 122.4f;
  return 90.0f;
}

static bool pca0Ok = false;
static bool pca1Ok = false;
static uint16_t lastPulse[SERVO_COUNT];

// calRef: hip = mount DEFAULT; thigh/shin = mechanical MAX.
// dir: +1 = PWM increases toward model MIN.
// lockedSpan*: 0 = use degree formula; else shared PWM ticks for that joint type.
static uint16_t calRef[JOINT_COUNT];
static int8_t calDir[JOINT_COUNT];
static uint16_t lockedSpanThigh = 0;
static uint16_t lockedSpanShin = 0;

static uint8_t uiToGlobal(uint8_t ui) { return ui - 1; }
static bool boardOk(uint8_t globalCh) {
  return (globalCh < 16) ? pca0Ok : pca1Ok;
}

static uint16_t idealSpan(uint8_t ji) {
  return (uint16_t)lroundf(jointHalfOrFullDeg(ji) * TICKS_PER_DEG);
}

// Room from this joint's MAX toward MIN before hitting pulse rails.
static uint16_t availableSpan(uint8_t ji) {
  if (!calRef[ji] || isHip(ji)) return 0;
  int32_t room = (calDir[ji] > 0)
                     ? ((int32_t)PULSE_HI - (int32_t)calRef[ji])
                     : ((int32_t)calRef[ji] - (int32_t)PULSE_LO);
  if (room < 0) room = 0;
  uint16_t ideal = idealSpan(ji);
  return (uint16_t)((uint32_t)room < ideal ? room : ideal);
}

static uint16_t pulseDelta(uint8_t ji) {
  if (isThigh(ji) && lockedSpanThigh) return lockedSpanThigh;
  if (isShin(ji) && lockedSpanShin) return lockedSpanShin;
  return idealSpan(ji);
}

static uint16_t clampPulse(int32_t p) {
  return (uint16_t)constrain(p, (int32_t)PULSE_LO, (int32_t)PULSE_HI);
}

static uint16_t derivedMin(uint8_t ji) {
  if (!calRef[ji]) return 0;
  return clampPulse((int32_t)calRef[ji] + (int32_t)calDir[ji] * (int32_t)pulseDelta(ji));
}

static uint16_t derivedMax(uint8_t ji) {
  if (!calRef[ji]) return 0;
  if (isHip(ji)) {
    return clampPulse((int32_t)calRef[ji] - (int32_t)calDir[ji] * (int32_t)pulseDelta(ji));
  }
  return calRef[ji];
}

static uint16_t derivedMid(uint8_t ji) {
  if (!calRef[ji]) return 0;
  if (isHip(ji)) return calRef[ji];
  return (uint16_t)((derivedMax(ji) + derivedMin(ji)) / 2);
}

// Park pose: hips DEFAULT, shins MID, thighs 75% of the way from MID toward MIN.
static uint16_t restPulse(uint8_t ji) {
  if (!calRef[ji]) return PULSE_DEFAULT;
  if (!isThigh(ji)) return derivedMid(ji);
  int32_t mid = (int32_t)derivedMid(ji);
  int32_t mn = (int32_t)derivedMin(ji);
  return clampPulse(mid + (int32_t)lroundf(0.75f * (float)(mn - mid)));
}

// Shortest available max→min among calibrated joints of a type; 0 if none ready.
static uint16_t shortestAvailable(bool thigh) {
  uint16_t best = 0xFFFF;
  uint8_t n = 0;
  for (uint8_t i = 0; i < JOINT_COUNT; i++) {
    if (thigh ? !isThigh(i) : !isShin(i)) continue;
    if (!calRef[i]) continue;
    uint16_t a = availableSpan(i);
    n++;
    if (a < best) best = a;
  }
  if (n == 0 || best == 0xFFFF) return 0;
  return best;
}

static void saveLockedSpans() {
  prefs.begin("servo_cal", false);
  prefs.putUShort("spanTh", lockedSpanThigh);
  prefs.putUShort("spanSh", lockedSpanShin);
  prefs.end();
}

// Recompute and store locked spans from current calibration (all 6 of a type if present).
static String lockShortestSpans() {
  uint16_t th = shortestAvailable(true);
  uint16_t sh = shortestAvailable(false);
  uint8_t nTh = 0, nSh = 0;
  for (uint8_t i = 0; i < JOINT_COUNT; i++) {
    if (isThigh(i) && calRef[i]) nTh++;
    if (isShin(i) && calRef[i]) nSh++;
  }
  String msg;
  if (nTh == 6 && th > 0) {
    lockedSpanThigh = th;
    msg += "thigh span locked=" + String(th);
  } else {
    msg += "thigh not locked (" + String(nTh) + "/6)";
  }
  msg += " · ";
  if (nSh == 6 && sh > 0) {
    lockedSpanShin = sh;
    msg += "shin span locked=" + String(sh);
  } else {
    msg += "shin not locked (" + String(nSh) + "/6)";
  }
  saveLockedSpans();
  return msg;
}

static void setServoPulse(uint8_t globalCh, uint16_t pulse) {
  if (globalCh >= SERVO_COUNT || !boardOk(globalCh)) return;
  pulse = constrain(pulse, PULSE_LO, PULSE_HI);
  if (globalCh < 16) pwm0.setPWM(globalCh, 0, pulse);
  else pwm1.setPWM(globalCh - 16, 0, pulse);
  lastPulse[globalCh] = pulse;
  Serial.printf("ch%u pulse=%u\n", globalCh, pulse);
}

static void loadCal() {
  prefs.begin("servo_cal", true);
  for (uint8_t i = 0; i < JOINT_COUNT; i++) {
    char k[12];
    snprintf(k, sizeof(k), "ref%u", i);
    uint16_t r = prefs.getUShort(k, 0);
    if (!r) {
      if (!isHip(i)) {
        snprintf(k, sizeof(k), "max%u", i);
        r = prefs.getUShort(k, 0);
      }
    }
    calRef[i] = r;
    snprintf(k, sizeof(k), "dir%u", i);
    int8_t d = (int8_t)prefs.getChar(k, -1);
    calDir[i] = (d == 1) ? 1 : -1;
  }
  lockedSpanThigh = prefs.getUShort("spanTh", 0);
  lockedSpanShin = prefs.getUShort("spanSh", 0);
  prefs.end();
}

static uint8_t calibratedCount() {
  uint8_t n = 0;
  for (uint8_t i = 0; i < JOINT_COUNT; i++) if (calRef[i]) n++;
  return n;
}

// Copy the committed snapshot into RAM (does not write NVS by itself).
static void applyBackupToRam() {
  for (uint8_t i = 0; i < JOINT_COUNT && i < CAL_BACKUP_COUNT; i++) {
    calRef[i] = CAL_BACKUP_REF[i];
    calDir[i] = (CAL_BACKUP_DIR[i] >= 0) ? 1 : -1;
  }
  lockedSpanThigh = CAL_BACKUP_SPAN_THIGH;
  lockedSpanShin = CAL_BACKUP_SPAN_SHIN;
}

static void persistAllCal() {
  prefs.begin("servo_cal", false);
  for (uint8_t i = 0; i < JOINT_COUNT; i++) {
    char k[12];
    snprintf(k, sizeof(k), "ref%u", i);
    prefs.putUShort(k, calRef[i]);
    snprintf(k, sizeof(k), "dir%u", i);
    prefs.putChar(k, (char)calDir[i]);
  }
  prefs.putUShort("spanTh", lockedSpanThigh);
  prefs.putUShort("spanSh", lockedSpanShin);
  prefs.end();
}

// Use the JSON snapshot if this chip has never been calibrated.
static void restoreBackupIfEmpty() {
  if (calibratedCount() > 0) return;
  applyBackupToRam();
  persistAllCal();
  Serial.println("NVS empty — restored calibration/servo_cal.json snapshot");
}

static void saveRef(uint8_t ji, uint16_t pulse) {
  calRef[ji] = pulse;
  prefs.begin("servo_cal", false);
  char k[12];
  snprintf(k, sizeof(k), "ref%u", ji);
  prefs.putUShort(k, pulse);
  prefs.end();
}

static void saveDir(uint8_t ji, int8_t dir) {
  calDir[ji] = (dir >= 0) ? 1 : -1;
  prefs.begin("servo_cal", false);
  char k[12];
  snprintf(k, sizeof(k), "dir%u", ji);
  prefs.putChar(k, (char)calDir[ji]);
  prefs.end();
}

static bool i2cPresent(uint8_t addr) {
  Wire.beginTransmission(addr);
  return Wire.endTransmission() == 0;
}

static String calJson() {
  String s = "{\"ticks_per_deg\":";
  s += String(TICKS_PER_DEG, 3);
  s += ",\"locked_span_thigh\":";
  s += lockedSpanThigh;
  s += ",\"locked_span_shin\":";
  s += lockedSpanShin;
  s += ",\"joints\":[";
  for (uint8_t i = 0; i < JOINT_COUNT; i++) {
    if (i) s += ',';
    uint8_t ch = uiToGlobal(JOINTS[i].ui);
    s += "{\"i\":";
    s += i;
    s += ",\"leg\":\"";
    s += JOINTS[i].leg;
    s += "\",\"joint\":\"";
    s += JOINTS[i].joint;
    s += "\",\"mode\":\"";
    s += isHip(i) ? "default" : "max";
    s += "\",\"ui\":";
    s += JOINTS[i].ui;
    s += ",\"ch\":";
    s += ch;
    s += ",\"range_deg\":";
    s += String(isHip(i) ? 90.0f : jointHalfOrFullDeg(i), 1);
    s += ",\"span\":";
    s += pulseDelta(i);
    s += ",\"available\":";
    s += availableSpan(i);
    s += ",\"dir\":";
    s += calDir[i];
    s += ",\"pulse\":";
    s += lastPulse[ch];
    s += ",\"ref\":";
    s += calRef[i];
    s += ",\"max\":";
    s += derivedMax(i);
    s += ",\"min\":";
    s += derivedMin(i);
    s += ",\"mid\":";
    s += derivedMid(i);
    s += '}';
  }
  s += "]}";
  return s;
}

static const char INDEX_HTML[] PROGMEM = R"HTML(
<!DOCTYPE html>
<html>
<head>
  <meta charset="utf-8"/>
  <meta name="viewport" content="width=device-width, initial-scale=1"/>
  <title>Servo calibration</title>
  <style>
    body { font-family: system-ui, sans-serif; max-width: 640px; margin: 16px auto; padding: 0 12px; }
    h1 { font-size: 1.15rem; margin: 0 0 6px; }
    h2 { font-size: 1rem; margin: 16px 0 6px; border-bottom: 1px solid #ddd; padding-bottom: 4px; }
    #info { font-size: 0.88rem; color: #333; margin-bottom: 8px; }
    .howto { font-size: 0.85rem; background: #f4f6fa; padding: 10px 12px; border-radius: 6px; line-height: 1.45; }
    .all { width: 100%; padding: 9px; margin: 4px 0; font-size: 0.9rem; }
    .row { border-bottom: 1px solid #e6e6e6; padding: 10px 0; }
    .label { font-weight: 650; margin-bottom: 4px; }
    .meta { font-weight: 400; opacity: 0.6; font-size: 0.82rem; }
    .cal { font-size: 0.8rem; margin: 2px 0 6px; font-variant-numeric: tabular-nums; line-height: 1.35; }
    .cal .ok { color: #1a7f37; }
    .cal .miss { color: #b54708; }
    .controls, .nudge, .save { display: flex; gap: 5px; align-items: center; flex-wrap: wrap; margin-top: 4px; }
    .controls { flex-wrap: nowrap; }
    input[type=range] { flex: 1; min-width: 120px; }
    .val { min-width: 3.2rem; text-align: right; font-variant-numeric: tabular-nums; }
    button { padding: 5px 8px; font-size: 0.85rem; }
    button.pri { background: #1f6feb; color: #fff; border: 1px solid #1f6feb; border-radius: 4px; }
    button.sec { background: #fff; border: 1px solid #bbb; border-radius: 4px; }
    button.dir { min-width: 4.6rem; font-weight: 650; }
    button.dir.on { background: #111; color: #fff; border-color: #111; }
    #status { min-height: 1.2em; margin-top: 12px; white-space: pre-wrap; font-size: 0.88rem; }
  </style>
</head>
<body>
  <h1>Servo calibration</h1>
  <div class="howto">
    <b>Model standard</b> (same on every leg; mirrors = Direction only):<br/>
    · <b>Hip</b> = save mount default only (no min/max). Side buttons mark which way is <b>+CCW</b> from above.<br/>
    · <b>Thigh +</b> = knee rises · MAX=folded hard stop · MIN=straight/flat<br/>
    · <b>Shin +</b> = foot folds under · MAX=folded hard stop · MIN=straight<br/>
    Thigh/shin: tap <b>MIN</b> on the slider side toward model MIN after saving MAX.
  </div>
  <p id="info">Loading…</p>
  <p><a href="/walk"><b>Gait preview →</b></a> (walk &amp; spin tabs)</p>
  <button class="all" onclick="lockSpans()">Lock thighs/shins to shortest max→min span</button>
  <button class="all" onclick="gotoGroup('thigh','max')">All thighs → MAX</button>
  <button class="all" onclick="gotoGroup('thigh','mid')">All thighs → MID</button>
  <button class="all" onclick="gotoGroup('thigh','min')">All thighs → MIN</button>
  <button class="all" onclick="gotoGroup('shin','max')">All shins → MAX</button>
  <button class="all" onclick="gotoGroup('shin','mid')">All shins → MID</button>
  <button class="all" onclick="gotoGroup('shin','min')">All shins → MIN</button>
  <button class="all" onclick="gotoAll('mid')">All calibrated → MID / DEFAULT</button>
  <button class="all" onclick="exportCal()">Download calibration JSON</button>
  <button class="all" onclick="restoreCal()">Restore snapshot from firmware backup</button>
  <div id="list"></div>
  <p id="status"></p>
  <script>
    const JOINTS = [
      { leg:'FL', joint:'hip',   ui:12 },
      { leg:'FL', joint:'thigh', ui:8 },
      { leg:'FL', joint:'shin',  ui:22 },
      { leg:'ML', joint:'hip',   ui:11 },
      { leg:'ML', joint:'thigh', ui:7 },
      { leg:'ML', joint:'shin',  ui:21 },
      { leg:'RL', joint:'hip',   ui:10 },
      { leg:'RL', joint:'thigh', ui:5 },
      { leg:'RL', joint:'shin',  ui:17 },
      { leg:'FR', joint:'hip',   ui:23 },
      { leg:'FR', joint:'thigh', ui:19 },
      { leg:'FR', joint:'shin',  ui:13 },
      { leg:'MR', joint:'hip',   ui:29 },
      { leg:'MR', joint:'thigh', ui:28 },
      { leg:'MR', joint:'shin',  ui:9 },
      { leg:'RR', joint:'hip',   ui:26 },
      { leg:'RR', joint:'thigh', ui:18 },
      { leg:'RR', joint:'shin',  ui:1 },
    ];
    const PULSE_LO = 80, PULSE_HI = 520, PULSE_DEFAULT = 300;
    const list = document.getElementById('list');
    const status = document.getElementById('status');
    const info = document.getElementById('info');
    const timers = {};
    const rows = [];
    const isHip = (j) => j.joint === 'hip';

    function boardLabel(ui) { return ui <= 16 ? '0x40' : '0x41'; }
    function localCh(ui) { return (ui - 1) % 16; }
    function constrain(v, lo, hi) { return Math.min(hi, Math.max(lo, v)); }

    let lastLeg = '';
    JOINTS.forEach((j, i) => {
      if (j.leg !== lastLeg) {
        lastLeg = j.leg;
        const h = document.createElement('h2');
        h.textContent = j.leg;
        list.appendChild(h);
      }
      const ch = j.ui - 1;
      const hip = isHip(j);
      const saveLabel = hip ? 'Save DEFAULT' : 'Save MAX';
      const hint = hip
        ? ' · +model=CCW from above · Save DEFAULT only (no min/max)'
        : (j.joint === 'thigh'
          ? ' · +model=knee up · Save at folded MAX · MIN = open/flat'
          : ' · +model=fold under · Save at folded MAX · MIN = straight');
      // Hip: side = which way is +CCW. Thigh/shin: side = which way is model MIN.
      // calDir +1 => higher PWM toward model MIN (−hip / open thigh-shin).
      const leftDir = hip ? 1 : -1;
      const rightDir = hip ? -1 : 1;
      const leftLbl = hip ? '← +CCW' : 'MIN ←';
      const rightLbl = hip ? '+CCW →' : '→ MIN';
      const row = document.createElement('div');
      row.className = 'row';
      row.innerHTML =
        '<div class="label">' + j.leg + ' ' + j.joint +
        ' <span class="meta">ui#' + j.ui + ' · ' + boardLabel(j.ui) + ' ch' + localCh(j.ui) +
        hint + '</span></div>' +
        '<div class="cal" data-cal></div>' +
        '<div class="nudge">' +
        '<button class="sec" data-n="-10">-10</button>' +
        '<button class="sec" data-n="-1">-1</button>' +
        '<button class="sec" data-n="1">+1</button>' +
        '<button class="sec" data-n="10">+10</button>' +
        '</div>' +
        '<div class="controls">' +
        '<button class="sec dir" data-dir="' + leftDir + '">' + leftLbl + '</button>' +
        '<input type="range" min="' + PULSE_LO + '" max="' + PULSE_HI + '" value="' + PULSE_DEFAULT + '" step="1"/>' +
        '<span class="val">' + PULSE_DEFAULT + '</span>' +
        '<button class="sec dir" data-dir="' + rightDir + '">' + rightLbl + '</button>' +
        '</div>' +
        '<div class="save">' +
        '<button class="pri" data-save="1">' + saveLabel + '</button>' +
        (hip
          ? '<button class="sec" data-goto="mid">Go DEFAULT</button>'
          : '<button class="sec" data-goto="max">Go MAX</button>' +
            '<button class="sec" data-goto="mid">Go MID</button>' +
            '<button class="sec" data-goto="min">Go MIN</button>') +
        '</div>';
      const range = row.querySelector('input');
      const val = row.querySelector('.val');
      const calEl = row.querySelector('[data-cal]');
      const dirBtns = row.querySelectorAll('[data-dir]');
      const setPulseUI = (p) => { range.value = p; val.textContent = p; };
      const setDirUI = (d) => {
        dirBtns.forEach(b => b.classList.toggle('on', +b.dataset.dir === d));
      };
      dirBtns.forEach(btn => {
        btn.onclick = () => setDir(i, +btn.dataset.dir, setDirUI);
      });
      row.querySelectorAll('[data-n]').forEach(btn => {
        btn.onclick = () => {
          const p = constrain(+range.value + (+btn.dataset.n), PULSE_LO, PULSE_HI);
          setPulseUI(p);
          movePulse(ch, p);
        };
      });
      range.oninput = () => {
        val.textContent = range.value;
        const p = +range.value;
        clearTimeout(timers[ch]);
        timers[ch] = setTimeout(() => movePulse(ch, p), 60);
      };
      row.querySelector('[data-save]').onclick = () => saveRef(i, +range.value);
      row.querySelectorAll('[data-goto]').forEach(btn => {
        btn.onclick = () => gotoCal(i, btn.dataset.goto, setPulseUI);
      });
      list.appendChild(row);
      rows.push({ i, ch, j, hip, range, val, calEl, setPulseUI, setDirUI });
    });

    function fmtCal(c) {
      if (c.mode === 'default') {
        const side = c.dir > 0 ? '+CCW on left (←)' : '+CCW on right (→)';
        if (!c.ref) {
          return '<span class="miss">default=unset</span> · ' + side + ' · now=' + c.pulse;
        }
        return '<span class="ok">default=' + c.ref + '</span> · ' + side + ' · now=' + c.pulse;
      }
      const dir = c.dir > 0 ? 'MIN on right (→ higher pulse)' : 'MIN on left (← lower pulse)';
      if (!c.ref) {
        return '<span class="miss">max=unset</span> · ' + dir + ' · now=' + c.pulse;
      }
      return '<span class="ok">max=' + c.max + '</span>' +
        ' → <span class="ok">mid=' + c.mid + '</span>' +
        ' → <span class="ok">min=' + c.min + '</span>' +
        ' · span=' + c.span + ' (avail ' + c.available + ')' +
        ' · ' + dir + ' · now=' + c.pulse;
    }

    async function refresh() {
      try {
        info.textContent = await (await fetch('/api/status')).text();
        const data = await (await fetch('/api/cal')).json();
        const lockNote = ' · locked thigh span=' + (data.locked_span_thigh || 'off') +
          ' · shin span=' + (data.locked_span_shin || 'off');
        info.textContent += lockNote;
        data.joints.forEach((c, idx) => {
          const r = rows[idx];
          if (!r) return;
          r.calEl.innerHTML = fmtCal(c);
          r.setDirUI(c.dir);
          if (c.pulse) r.setPulseUI(c.pulse);
        });
      } catch (e) {
        info.textContent = 'Cannot reach ESP';
      }
    }

    async function movePulse(ch, pulse) {
      try {
        const r = await fetch('/api/pulse?ch=' + ch + '&pulse=' + pulse);
        status.textContent = r.ok ? ('ch' + ch + ' → ' + pulse) : await r.text();
      } catch (e) { status.textContent = 'Request failed'; }
    }

    async function setDir(i, dir, setDirUI) {
      try {
        status.textContent = await (await fetch('/api/cal/dir?i=' + i + '&dir=' + dir)).text();
        setDirUI(dir);
        await refresh();
      } catch (e) { status.textContent = 'Dir failed'; }
    }

    async function saveRef(i, pulse) {
      try {
        status.textContent = await (await fetch('/api/cal/save?i=' + i + '&pulse=' + pulse)).text();
        await refresh();
      } catch (e) { status.textContent = 'Save failed'; }
    }

    async function gotoCal(i, which, setPulseUI) {
      try {
        const t = await (await fetch('/api/cal/goto?i=' + i + '&which=' + which)).text();
        status.textContent = t;
        const m = t.match(/pulse=(\d+)/);
        if (m) setPulseUI(+m[1]);
        await refresh();
      } catch (e) { status.textContent = 'Goto failed'; }
    }

    async function gotoAll(which) {
      try {
        status.textContent = await (await fetch('/api/cal/all?which=' + which)).text();
        await refresh();
      } catch (e) { status.textContent = 'Failed'; }
    }

    async function gotoGroup(joint, which) {
      try {
        status.textContent = await (await fetch('/api/cal/group?joint=' + joint + '&which=' + which)).text();
        await refresh();
      } catch (e) { status.textContent = 'Failed'; }
    }
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
void loop() {
  server.handleClient();
  if (walkEnabled()) {
    uint32_t now = millis();
    float dt = (now - lastWalkMs) / 1000.f;
    lastWalkMs = now;
    walkUpdate(dt);
    applyWalkPose();
  } else {
    lastWalkMs = millis();
  }
}

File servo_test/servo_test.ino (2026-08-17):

#include <ESP32Servo.h>

Servo servo;
const int SERVO_PIN = 11;

// Center position; adjust if your horn zero is different
const int CENTER = 90;

void setup() {
  Serial.begin(115200);
  servo.setPeriodHertz(50);
  servo.attach(SERVO_PIN, 500, 2400);
  servo.write(CENTER);
  delay(1000);
  Serial.println("Servo test starting");
}

void loop() {
  // +45 degrees
  servo.write(CENTER + 45);
  Serial.println("Moved +45");
  delay(3000);

  // -45 degrees (back the other way, returns to center)
  servo.write(CENTER - 45);
  Serial.println("Moved -45");
  delay(3000);

  // Optional: return to center before next cycle
  servo.write(CENTER);
  delay(1000);
}

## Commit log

2026-08-17 Initial commit: hexapod kinematics, ESP32 firmware, and servo calibration snapshot.
    [body.urdf, hexapod.urdf, leg_one.urdf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]
2026-08-17 Give the 3D model real link bulk: 10 mm hips, 30 mm thighs, pointed shins, and a 30 mm chassis.
    [body.urdf, hexapod.urdf, leg_one.urdf]
2026-08-19 Expand docs so a new builder can set up, calibrate, and walk.
    Add calibration and troubleshooting guides, a fuller USAGE.md, and a README that points newcomers through hardware, flash, and first walk.
2026-08-19 Add planted stretch modes including chassis tilt.
    Pitch, crouch, and twist keep the body level. Roll, nod, and swirl actually tilt the plate so the robot has more stationary motion.
2026-08-19 Strip the GitHub README down to a pointer at USAGE and calibration docs.
